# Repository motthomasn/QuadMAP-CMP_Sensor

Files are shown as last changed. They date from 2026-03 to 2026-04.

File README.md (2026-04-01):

# QuadMAP-CMP_Sensor

Iteration of single MAP-CMP_Sensor described: https://github.com/motthomasn/MAP-CMP_Sensor 

Small module combining 4xMAP sensors and engine phase sensor (camshaft posn) for internal combustion engine management on 4-cylinder engines with individual port throttles.

This module was built for my CBR250RRi project. The aim was to allow an aftermarket ECU to achieve 720deg synchronisation or engine phase detection without the use of a physical camshaft position sensor being installed on the engine. 

The board uses NXP pressure sensors to measure the pressure pulses in each port. The pressure signal from cylinder 1 is passed to an LM397 comparator and compared to a reference voltage determined from a fixed voltage divider. 
The output signal from the comparator is normally high but when the pressure signal falls below the reference voltage, the output is pulled low. With the reference voltage set correctly, a reliable "cam position" signal can be achieved at engine idle
consisting of a single pulse per engine cycle.

**Note:** In a port throttled engine, the pressure signal may not be strong enough to produce a reliable signal throughout the engine speed/load range. In my application this is fine as the ECU I am working with (Life Racing F88R) allows the option to 
ignore the engine phase signal once 720deg synchronisation has been achieved. This means that the signal only has to be reliable during starting and idle.

The signals from all four pressure sensors are processed via LMV324 op-amps so that the output is always the minimum of the four individual signals. This ensures a more stable and reliable pressure signal for engine management.

### Sensor Pinout

Mating connector is JST JWPF 04R-JWPF-VSLE-S.

| Pin # | Description |
|:-----:|:---|
| 1 | CMP Signal |
| 2 | GND |
| 3 | +5V |
| 4 | MAP Signal |

## Breakout Details

A breakout connector is also included to access the individual raw pressure sensors for diagnostics or possibly throttle body balancing. 

**Wire gauge:**	0.35mm2  
**Sheath:**		Raychem DR-25 1/4"  
**Connector:**	DB9 Female. RS 765-9555  
**Wire Length:**	570mm. Case to back of connector

### Breakout Pinout

| Pin # | Description |
|:-----:|:---|
| 1 | map1 |
| 2 | map2 |
| 3 | map3 |
| 4 | map4 |
| 5 | GND |
| 6 | N/C |
| 7 | N/C |
| 8 | N/C |
| 9 | N/C |

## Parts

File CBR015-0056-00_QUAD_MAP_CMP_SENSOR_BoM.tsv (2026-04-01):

Designation | Description | Value | Manufacturer | Part Number | Package | Supplier | Stock No. / Order Code | Purchased | Notes
U1 | Comparator | 44μs, 30V | Texas Instruments | LM397MF/NOPB | SOT-23 | Farnell | 3118476 | Y
U2 | Pressure Sensor | 15-115 kPa | NXP | MPXA6115AC6U |  | RS | 719-1134 | Y
U3 | Pressure Sensor | 15-115 kPa | NXP | MPXA6115AC6U |  | RS | 719-1134
U4 | Pressure Sensor | 15-115 kPa | NXP | MPXA6115AC6U |  | RS | 719-1134
U5 | Pressure Sensor | 15-115 kPa | NXP | MPXA6115AC6U |  | RS | 719-1134
U6 | Quad Op-Amp |  | Texas Instruments | LMV324QD | SOIC-14 | RS | 732-0910
J1 | Connector | 4 way male | JST | B04B-JWPF-SK-R |  | Farnell | 1324127 | Y
J2 | Debug Connector | 4 way male |  |  |  | RS |  |  | Only used to facilitate connection to oscilloscope for initial testing & debug. May be removed in later revisions
J3 | Sync Connector | 5 way female
C1 | Pressure sensor power smooth cap | 100nF | AVX | 08055C104KAT2A | 805 | RS | 464-6688
C2 | Pressure sensor output smooth cap | 47pF | KEMET | C0805C470J5GACTU | 805 | RS | 264-4270
C3 | Pressure sensor power smooth cap | 100nF | AVX | 08055C104KAT2A | 805 | RS | 464-6688
C4 | Pressure sensor output smooth cap | 47pF | KEMET | C0805C470J5GACTU | 805 | RS | 264-4270
C5 | Pressure sensor power smooth cap | 100nF | AVX | 08055C104KAT2A | 805 | RS | 464-6688
C6 | Pressure sensor output smooth cap | 47pF | KEMET | C0805C470J5GACTU | 805 | RS | 264-4270
C7 | Pressure sensor power smooth cap | 100nF | AVX | 08055C104KAT2A | 805 | RS | 464-6688
C8 | Pressure sensor output smooth cap | 47pF | KEMET | C0805C470J5GACTU | 805 | RS | 264-4270
R1 | Comparator output pull-up resistor | 10K | TE Connectivity | CRG0805F10K | 805 | RS | 223-0562
R2 | Pressure sensor output filter resistor | 51K | Vishay | CRCW080551K0FKEA | 805 | RS | 679-1525
R3 | Pressure sensor output filter resistor | 51K | Vishay | CRCW080551K0FKEA | 805 | RS | 679-1525
R4 | Pressure sensor output filter resistor | 51K | Vishay | CRCW080551K0FKEA | 805 | RS | 679-1525
R5 | Pressure sensor output filter resistor | 51K | Vishay | CRCW080551K0FKEA | 805 | RS | 679-1525
R6 | Op-Amps Pull-Up Resistor | 1K | Bourns | CR0805-FX-1001ELF | 805 | RS | 740-8971
R7 | Ref Voltage Divider | 3.9K | TE Connectivity | CRG0805F3K9 | 805 | RS | 223-0506
R8 | Ref Voltage Divider | 5.9K | TE Connectivity | CPF0805B5K9E1 | 805 | RS | 123-3041
D1 |  | Quad 80V 300mA Common Anode | Toshiba | 1SS308(TE85L,F) | SOT-26 | RS | 579-604

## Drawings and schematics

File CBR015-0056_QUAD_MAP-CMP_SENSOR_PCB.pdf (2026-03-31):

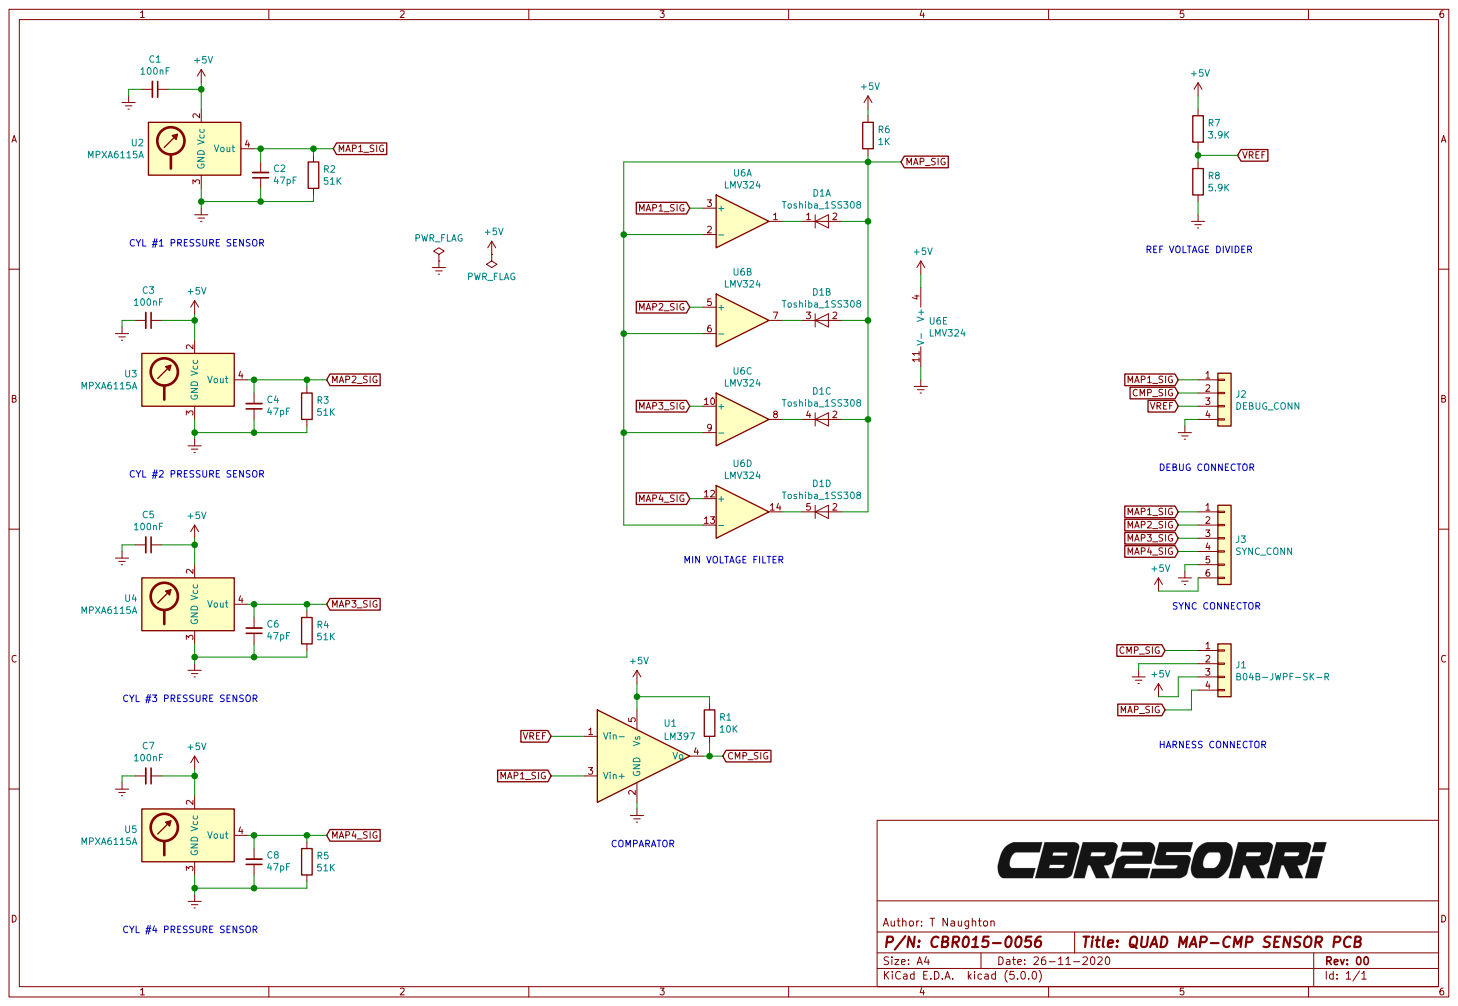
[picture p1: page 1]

CYL #2 PRESSURE SENSOR Vcc 2 GND

51K CYL #3 PRESSURE SENSOR Vcc 2 GND

51K CYL #4 PRESSURE SENSOR Vcc 2 GND

Id: 1/1 Title: QUAD MAP-CMP SENSOR PCB

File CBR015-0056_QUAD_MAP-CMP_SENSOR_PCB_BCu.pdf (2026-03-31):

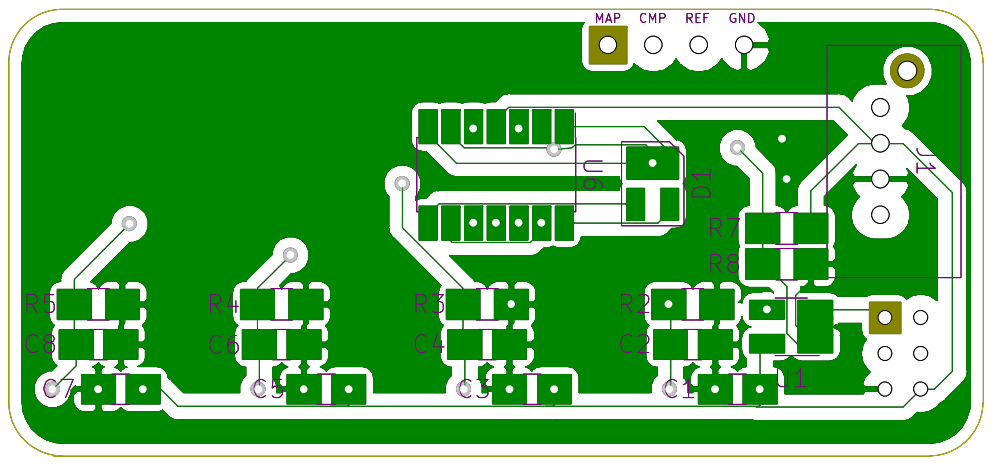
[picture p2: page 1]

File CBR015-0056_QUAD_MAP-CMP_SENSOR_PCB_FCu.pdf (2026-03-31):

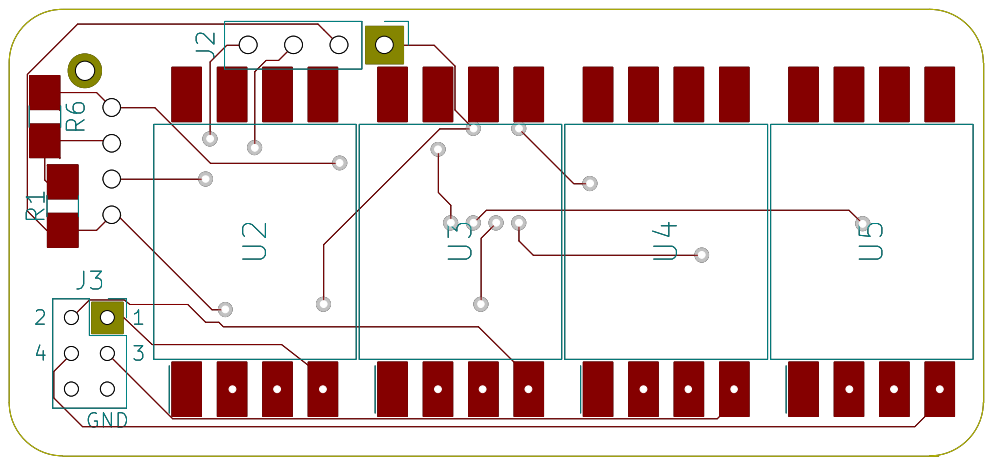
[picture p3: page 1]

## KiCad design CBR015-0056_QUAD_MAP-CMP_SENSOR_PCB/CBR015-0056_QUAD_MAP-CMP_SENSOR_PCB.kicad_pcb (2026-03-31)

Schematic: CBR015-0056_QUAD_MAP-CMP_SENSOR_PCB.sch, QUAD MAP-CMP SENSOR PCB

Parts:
C1, C3, C5, C7: 100nF; C_0805_HandSoldering
C2, C4, C6, C8: 47pF; C_0805_HandSoldering
D1: Toshiba_1SS308; SOT-26-5
J1: B04B-JWPF-SK-R; JST_B04B-JWPF-SK-R
J2: DEBUG_CONN; Pin_Header_Straight_1x04_Pitch2.54mm
J3: SYNC_CONN; Socket_Strip_Straight_2x03_Pitch2.00mm
R1: 10K; R_0805_HandSoldering
R2, R3, R4, R5: 51K; R_0805_HandSoldering
R6: 1K; R_0805_HandSoldering
R7: 3.9K; R_0805_HandSoldering
R8: 5.9K; R_0805_HandSoldering
U1: LM397; SOT-23-5_HandSoldering
U2, U3, U4, U5: MPXA6115A; 98ASB17757C
U6: LMV324; SOIC-14_3.9x8.7mm_Pitch1.27mm

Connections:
+5V: C1.1, C3.1, C5.1, C7.1, J1.3, J3.6, R1.1, R6.1, R7.1, U1.5, U2.2, U3.2, U4.2, U5.2, U6.4 (V+)
CMP_SIG: J1.1, J2.2, R1.2, U1.4
Earth: C1.2, C2.1, C3.2, C4.1, C5.2, C6.1, C7.2, C8.1, J1.2, J2.4, J3.5, R2.2, R3.2, R4.2, R5.2, R8.2, U1.2, U2.3, U3.3, U4.3, U5.3, U6.11 (V-)
MAP1_SIG: C2.2, J2.1, J3.1, R2.1, U1.3, U2.4, U6.3 (+)
MAP2_SIG: C4.2, J3.2, R3.1, U3.4, U6.5 (+)
MAP3_SIG: C6.2, J3.3, R4.1, U4.4, U6.10 (+)
MAP4_SIG: C8.2, J3.4, R5.1, U5.4, U6.12 (+)
MAP_SIG: D1.2, J1.4, R6.2, U6.2 (-), U6.6 (-), U6.9 (-), U6.13 (-)
unnamed: D1.1, U6.1
unnamed: D1.3, U6.7
unnamed: D1.4, U6.8
unnamed: D1.5, U6.14
VREF: J2.3, R7.2, R8.1, U1.1

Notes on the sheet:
HARNESS CONNECTOR
CYL #1 PRESSURE SENSOR
COMPARATOR
REF VOLTAGE DIVIDER
DEBUG CONNECTOR
CYL #2 PRESSURE SENSOR
CYL #3 PRESSURE SENSOR
CYL #4 PRESSURE SENSOR
SYNC CONNECTOR
MIN VOLTAGE FILTER

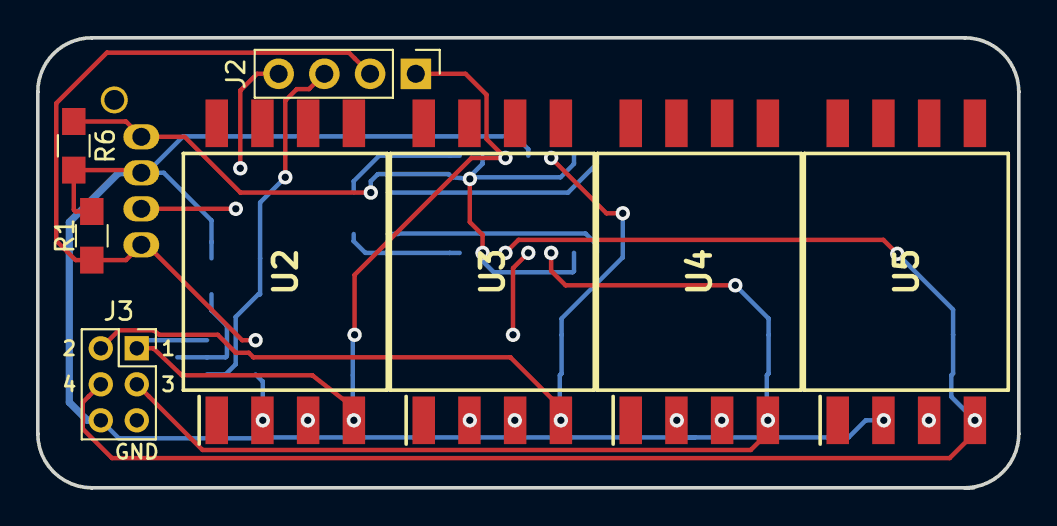
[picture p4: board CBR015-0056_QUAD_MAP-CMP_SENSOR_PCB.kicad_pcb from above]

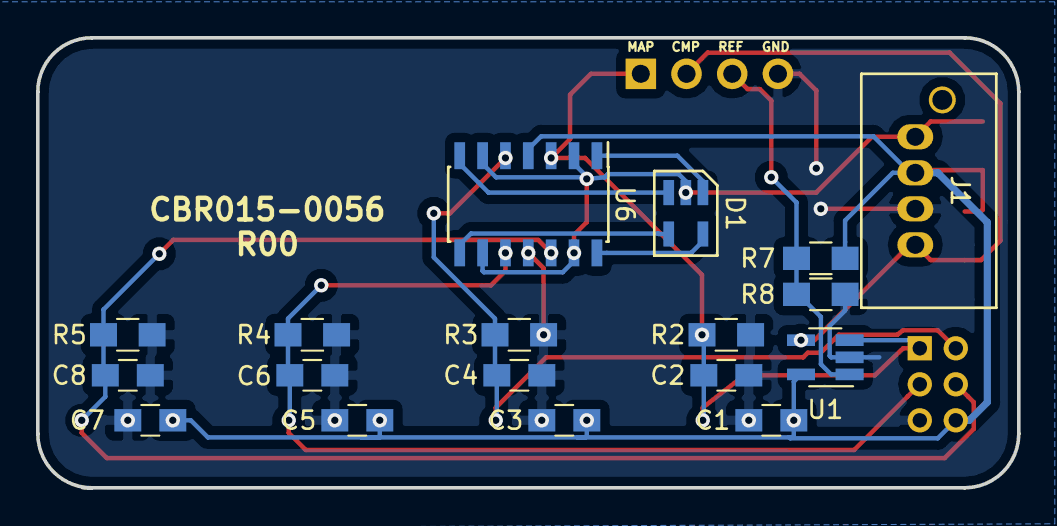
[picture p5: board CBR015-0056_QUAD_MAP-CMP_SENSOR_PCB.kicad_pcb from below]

Board: 2 copper layers, 54.5 x 25.0 mm, 26 parts (18 on the bottom side), 13 nets.

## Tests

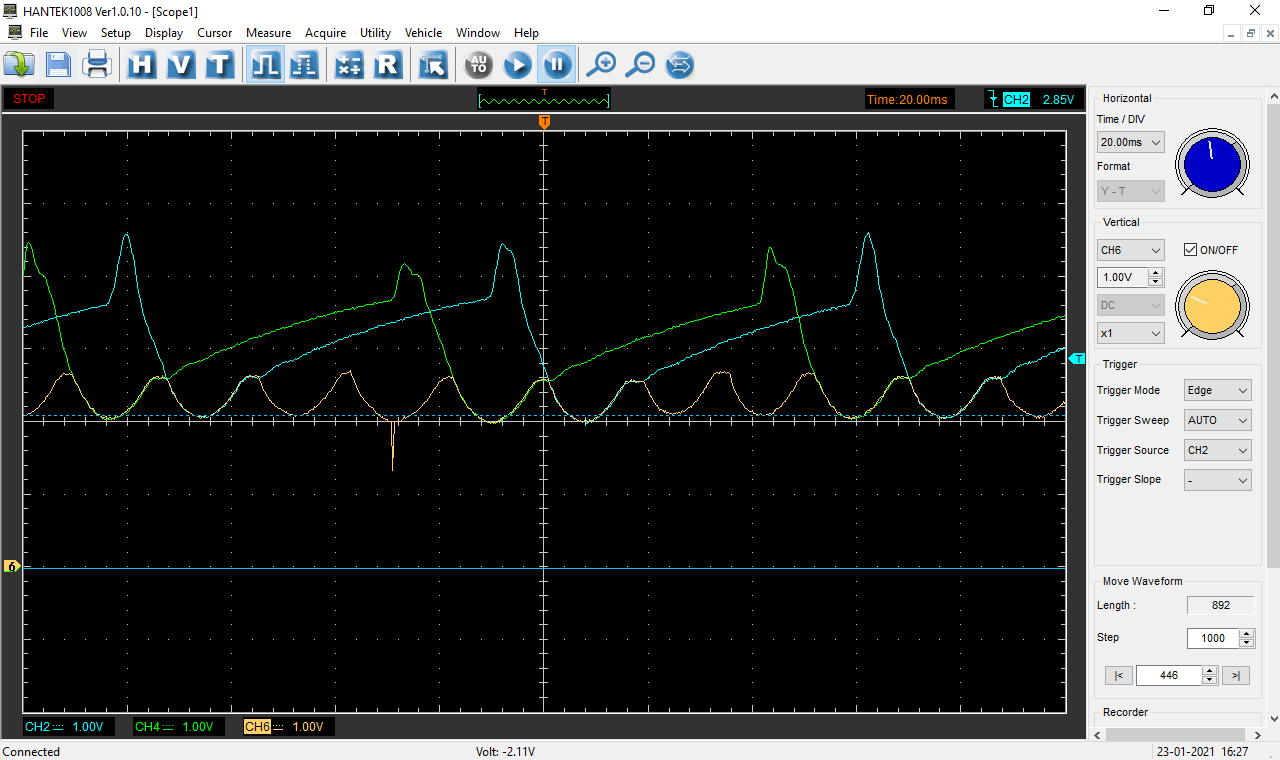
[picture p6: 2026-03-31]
Testing/Idle_Ch2Cyl1_Ch4Cyl3_Ch6ECUMAP.PNG

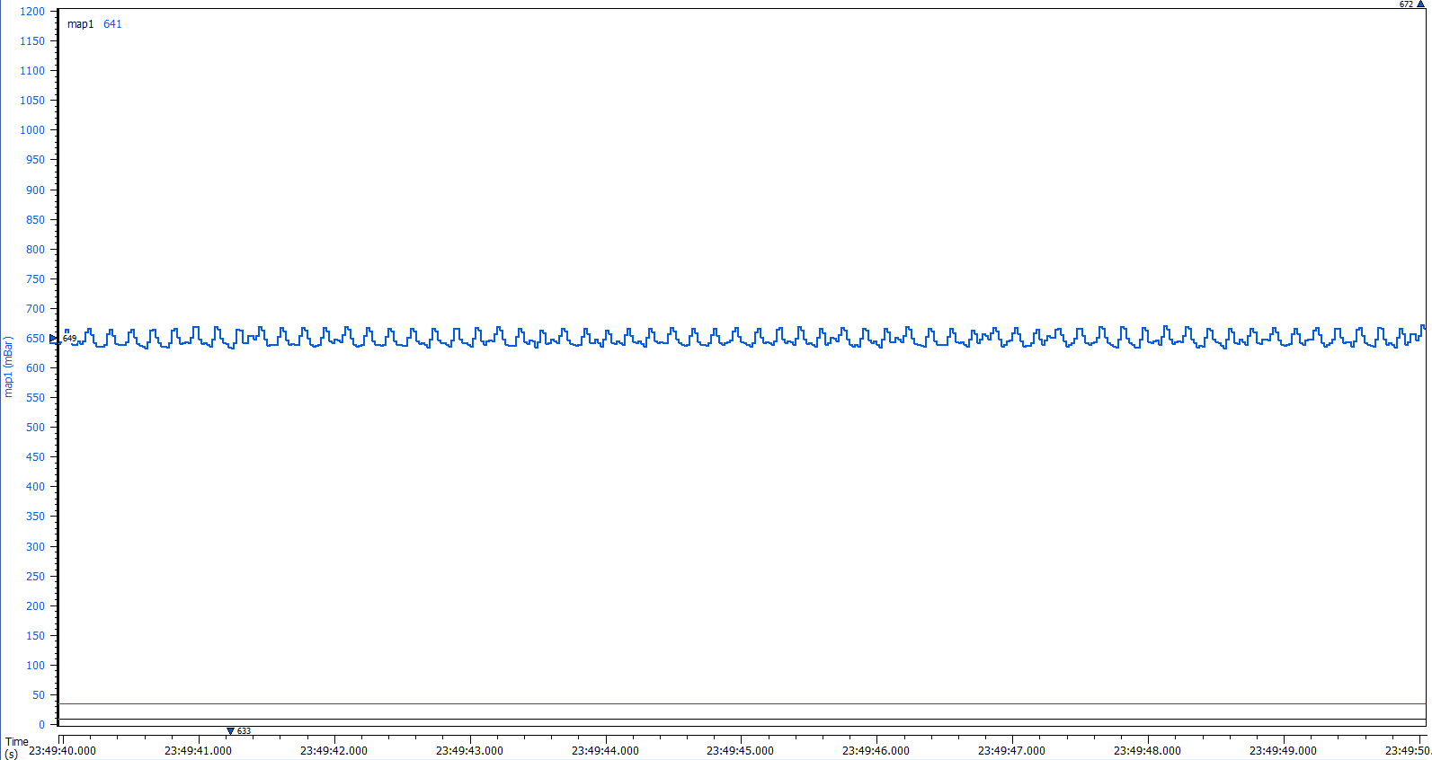
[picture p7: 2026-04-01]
Testing/Min-of-4ports_MAP.PNG

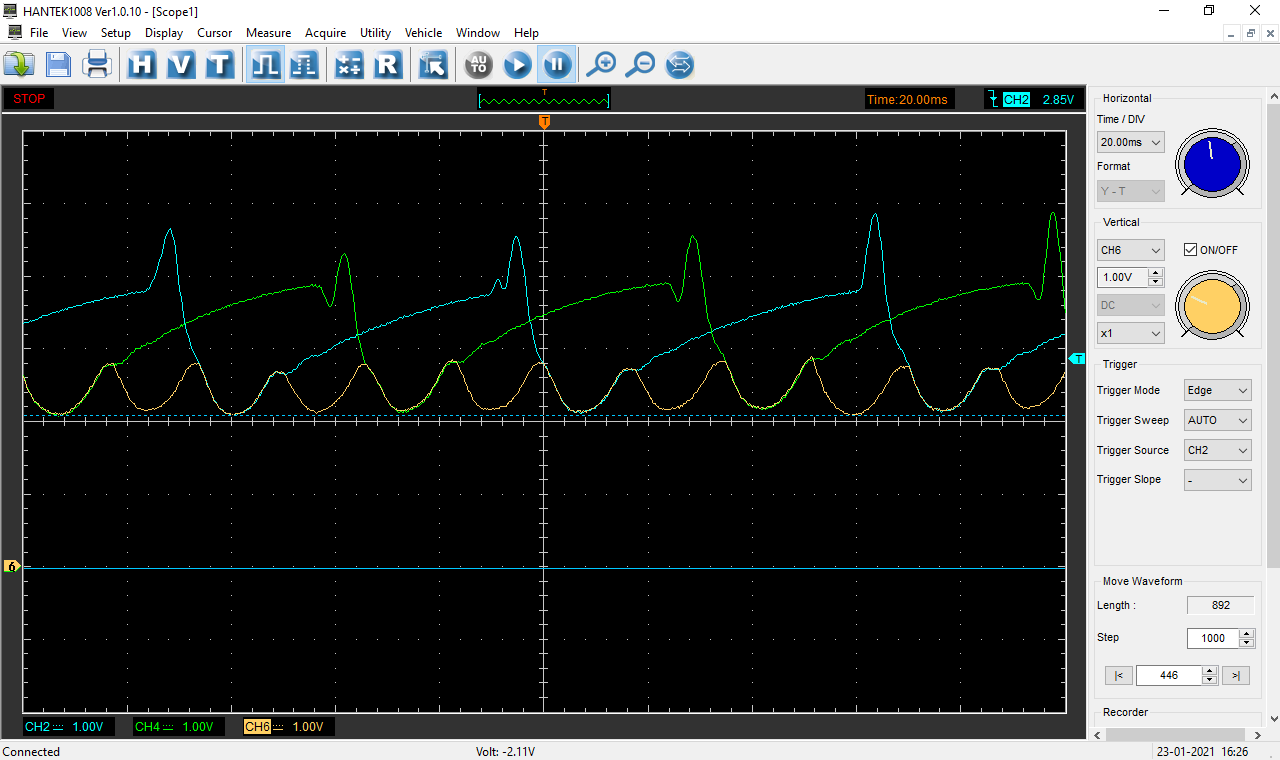
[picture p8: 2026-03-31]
Testing/Idle_Ch2Cyl1_Ch4Cyl4_Ch6ECUMAP.PNG

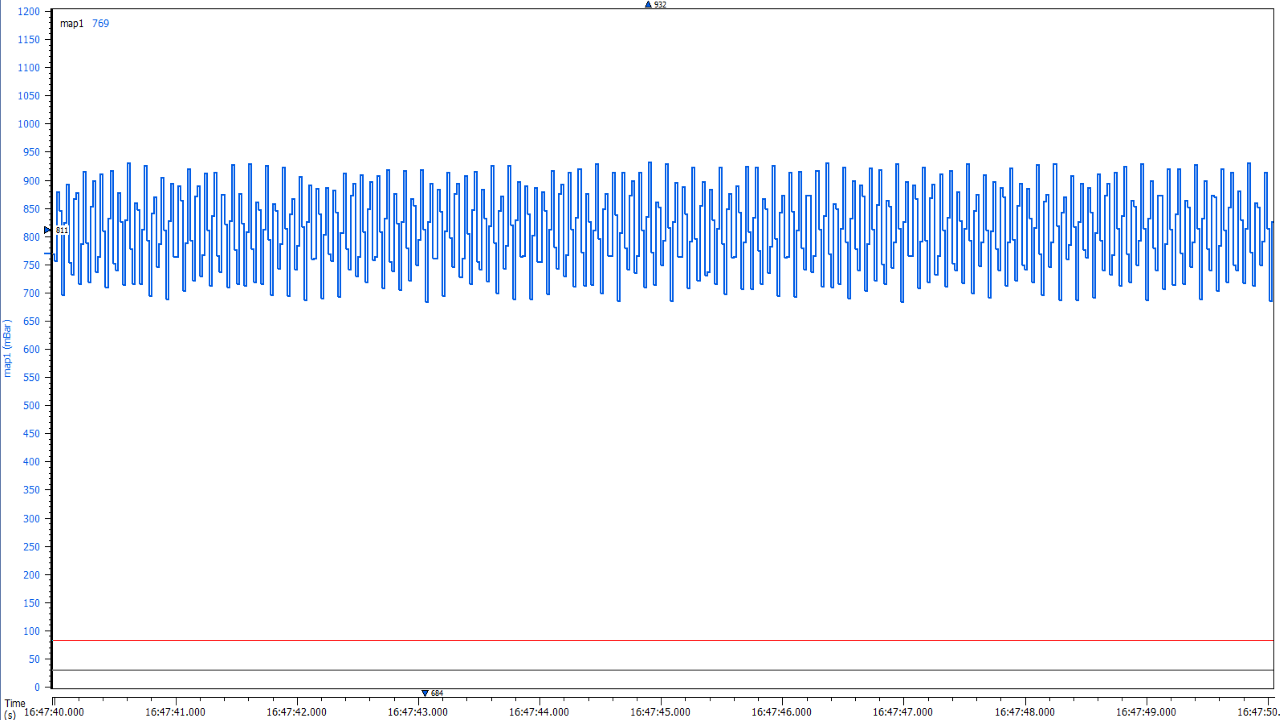
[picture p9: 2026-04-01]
Testing/Single_Port_MAP.PNG

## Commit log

2026-03-31 Initial commit from local
    [CBR015-0056_QUAD_MAP-CMP_SENSOR_PCB-B.Cu.gbl, CBR015-0056_QUAD_MAP-CMP_SENSOR_PCB-B.Mask.gbs, CBR015-0056_QUAD_MAP-CMP_SENSOR_PCB-B.SilkS.gbo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]
2026-04-01 Moved DB9 pinout to README.md file and removed Excel pinout
    [DB9_Pinout.xlsx]
2026-04-01 Removed .gsheet BoM & replaced with TSV file
    [CBR015-0056-00_QUAD_MAP_CMP_SENSOR_BoM.tsv]
